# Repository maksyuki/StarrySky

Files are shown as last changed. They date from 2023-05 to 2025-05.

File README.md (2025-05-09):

<p align="center">
    <!-- <img width="200px" src="./.images/tree_core_logo.svg" align="center" alt="Tree Core CPU" /> -->
    <h2 align="center">StarrySky: A series of Single-board Computers(SBCs) based on OSOC SoC</h2>
</p>
<p align="center">
    <a href="./LICENSE">
      
    </a>
    <a href="./CONTRIBUTING.md">
      
    </a>
    <a href="https://github.com/maksyuki/StarrySky">
      
    </a>
</p>

The StarrySky is now fully Open Source Hardware Association Certified.

UID:CN000018 https://certification.oshwa.org/list.html



Hardware, software and documentation licensed under the GPL v3 license.

## Guide
* StarrySky introduction: https://ysyx.oscc.cc/chip/board/official
* StarrySky V1.2: https://ysyx.oscc.cc/chip/board/official/boards/board-1
* StarrySky V1.3: https://ysyx.oscc.cc/chip/board/official/boards/board-2
* StarrySky V2.1: https://ysyx.oscc.cc/chip/board/official/boards/board-3
* StarrySky V3.0: come soon!
## Overview
The StarrySky SBC(Single Board Computer) was launched by Yuchi Miao in March 2023. It is used to evaluate and showcase the rich peripheral applications of the One Student One Chip SoC. The long-term goal is to build a lightweight software and hardware ecosystem around the Starry Sky boards and explore rich application scenarios in the field of education.







## License
All of the contents in this repo are release under the [GPL-3.0 License](LICENSE).

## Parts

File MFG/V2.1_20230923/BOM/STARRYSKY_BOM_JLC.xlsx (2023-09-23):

Comment | Designator | Footprint | Quantity
10uF | CP1,CP2 | AEC-2-5R40X4R00-SM | 2
0.1uF | C1,C2,C8,C9,C12,C13,C17,C18,C19,C20,C27,C28,C29,C30,C31,C32,C33,C34,C35,C36,C37,C38,C41,C42,C43,C44,C45,C46,C47,C48,C49,C50,C51,C52,C53,C54,C55,C56,C57,C58,C59,C60,C61,C62,C63,C64,C66,C67,C68,C69,C71,C72,C73,C74,C76,C78,C79,C80,C81,C82,C83,C84,C85,C86,C88,C89,C90,C91,C92,C93,C97,C98,C99,C101,C104,C105,C106,C107,C108,C110,C112,C115,C116,C117,C118,C119,C120,C121,C122,C123,C124,C125,C126,C128,C129,C131,C134,C144,C146,C148,C149,C155,C156,C160,C162,C163,C164,C165,C166,C167,C168,C170,C172,C174,C176,C177,C181,C182,C183,C185,C186,C192 | C0402 | 122
10uF | C3,C5,C6,C10,C11,C14,C21,C23,C24,C25,C26,C70,C87,C94,C95,C103,C130,C132,C133,C150,C169,C171,C173 | C0402 | 23
1uF | C4,C15,C22,C65,C102,C143,C145,C147,C154,C157,C161,C175,C178 | C0402 | 13
15pF | C7,C16,C109,C111 | C0402 | 4
22nF | C39 | C0402 | 1
10nF | C40 | C0402 | 1
10pF | C75,C77 | C0402 | 2
18pF | C96,C100 | C0402 | 2
100pF | C113 | C0402 | 1
47pF | C114 | C0402 | 1
2.2uF | C127 | C0402 | 1
22uF | C135,C136,C137,C138,C139,C141 | C0402 | 6
20pF | C140,C142,C151,C152,C153 | C0402 | 5
39pF | C158,C159,C179,C180 | C0402 | 4
330pF | C184,C187,C189,C190 | C0402 | 4
NC | C188,C191 | C0402 | 2
SMAJ5.0CA | D1 | SMA-2R00X1R80 | 1
0805_2A | F1 | L0805 | 1
FIXING-HOLE | H1,H2,H3,H4 | HOLE-3R10-4R10 | 4
USB_PWR | J1 | USB-TYPEC-12-SM | 1
100MHz | J2 | XTAL-4-3R20X2R50-SM | 1
DC_PWR | J3 | USB-TYPEC-12-SM | 1
25MHz | J4 | XTAL-4-3R20X2R50-SM | 1
SD_MICRO | J5,J7 | SD-MICRO-9-SM | 2
ACA-SPI-004-K02 | J6,J13 | ACA-SPI-004-K02-SM | 2
JTAG | J8 | HDR5X2-2R54-TM-VF | 1
PS_PWR | J9 | USB-TYPEC-12-SM | 1
USB_HOST | J10 | USB-STD-TYPEA-4-SM | 1
PS2_PURPLE | J11 | PS2-6-TM-VF | 1
VGA | J12 | DE-15-TM-RF | 1
FPC-8 | J14 | FPC-8-0R50-0R80X0R30 | 1
AUD_OUT | J15 | AV-6-2R30X1R60-SM | 1
PL_SD | J16 | SD-MICRO-9-SM | 1
AUD_IN | J17 | AV-6-2R30X1R60-SM | 1
LSPK | J18 | PH-2R00-TM-VM | 1
USB_PL_UART | J19 | USB-TYPEC-12-SM | 1
RSPK | J20 | PH-2R00-TM-VM | 1
PL_EXTN | J21 | HDR20X2-1R27-SM-VF | 1
DF40C-100DS-0.4V | J22,J23,J24,J25 | B2B-100-0R40-SM-VF | 4
RED | LED1 | LED0603 | 1
BLUE | LED2,LED3,LED4,LED5 | LED0603 | 4
WS2812C | LED6,LED7,LED8,LED9 | LED5050 | 4
600OHM@100MHz 1.5A | L1,L2,L3,L4,L5,L6,L7 | L0805 | 7
180OHM@100MHz 1.5A | L8,L9 | L0805 | 2
RUM001L02T2CL | Q1,Q2,Q3 | SOT-723-3-0R49X0R29 | 3
56K | R1 | R0402 | 1
2K | R2,R44,R60,R81,R104,R105,R110,R154,R156 | R0402 | 9
5.1K | R3,R7,R86,R89,R179,R181 | R0402 | 6
NC | R4,R6,R11,R12,R18,R69,R77,R83,R109,R111,R183 | R0402 | 11
33R | R5,R13,R51,R70,R99,R138,R140,R142,R147,R148,R149,R150,R151,R153,R155,R185 | R0402 | 16
4.7K | R8,R14,R48,R49,R50,R52,R53,R54,R55,R56,R57,R64,R65,R68,R72,R74,R75,R84,R91,R96,R103,R106,R107,R108,R128,R129,R130,R131,R144,R145,R146,R157,R159,R160,R173,R174,R176 | R0402 | 37
10K | R9,R15,R19,R34,R58,R61,R62,R63,R85,R88,R93,R112,R115,R133,R162,R163 | R0402 | 16
26K | R10 | R0402 | 1
8.06K | R16,R102 | R0402 | 2
1K | R17,R90,R152 | R0402 | 3
0R | R20,R22,R24,R30,R37,R38,R43,R45,R46,R47,R95,R98,R100,R101,R135,R137,R143,R158,R161,R164,R165,R168,R169,R170,R175,R177,R178,R180,R182,R184 | R0402 | 30
5K | R21,R23,R25,R28,R29,R31,R32,R33,R35,R36,R39,R40,R41,R42 | R0402 | 14
1M | R26,R97 | R0402 | 2
14K | R27 | R0402 | 1
330R | R59 | R0402 | 1
20K | R66,R67,R76,R78,R79,R80,R82 | R0402 | 7
150R | R71,R73 | R0402 | 2
22R | R87 | R0402 | 1
1.5K | R92 | R0402 | 1
100K | R94 | R0402 | 1
1740R | R113,R120,R124 | R0402 | 3
100R | R114,R118,R136,R139,R141 | R0402 | 5
866R | R116,R121,R125 | R0402 | 3
430R | R117,R122,R126 | R0402 | 3
215R | R119,R123,R127 | R0402 | 3
5.1R | R132 | R0402 | 1
4.7R | R134 | R0402 | 1
30K | R166,R167,R171,R172 | R0402 | 4
PWR-SEL1 | SW1 | SW-3-12R7X6R6 | 1
PWR-SEL2 | SW2 | SW-3-12R7X6R6 | 1
PWR-LOCK | SW3 | SW-6-LOCK-DPDT-TM | 1
PLL-SEL | SW4 | DIP-SW-4-1R27X0R76-SM | 1
CLK-SEL | SW5 | DIP-SW-8-1R52X0R76-SM | 1
SOC-RESET | SW6 | SW-4-1R20X0R65-SM | 1
CORE-SEL | SW7 | DIP-SW-6-1R27X0R76-SM | 1
HFP-SW | SW8 | SW-6-SLIDE-DPDT-TM | 1
HFP-RESET | SW9 | SW-4-1R20X0R65-SM | 1
HFP-BOOT | SW10 | SW-4-1R20X0R65-SM | 1
HFP-USER | SW11 | SW-4-1R20X0R65-SM | 1
PS-EXT-RESET | SW12 | SW-4-1R20X0R65-SM | 1
FPGA-BOOT | SW13 | DIP-SW-2-1R52X0R76-SM | 1
PS-PWR-RESET | SW14 | SW-4-1R20X0R65-SM | 1
PS-KEY1 | SW15 | SW-4-1R20X0R65-SM | 1
PS-KEY2 | SW16 | SW-4-1R20X0R65-SM | 1
PERIP-SW | SW17 | SW-6-SLIDE-DPDT-TM | 1
PL-KEY | SW18 | SW-4-1R20X0R65-SM | 1
PA-SW | SW19 | SW-6-SLIDE-DPDT-TM | 1
OSC_25M_IN | TP1 | TP1X1-1R00-SM | 1
OSC_100M_IN | TP2 | TP1X1-1R00-SM | 1
CLK4DIV | TP3 | TP1X1-1R00-SM | 1
HFP_VCC_3V3 | TP4 | TP1X1-1R00-SM | 1
HFP_SWDIO | TP5 | TP1X1-1R00-SM | 1
HFP_SWCLK | TP6 | TP1X1-1R00-SM | 1
HFP_GND | TP7 | TP1X1-1R00-SM | 1
RT2515H | U1,U2,U4 | SOIC-8-1R80X0R60-THRM | 3
SOC-28NM-202301 | U3 | LQFP-144-1R80X0R28 | 1
LPSDRAM_16X16 | U5 | FBGA-54-0R36-8R00X8R00 | 1
TPS3808G01 | U6 | SOT-23-6-1R10X0R60 | 1
WAS3157B | U7,U9,U10,U11,U12,U14,U26,U27,U29,U30,U31,U32,U33,U34,U35,U36,U37,U38,U39,U40,U44,U45 | SOT-363-6-0R80X0R40 | 22
CP2102 | U8,U22,U50 | QFN-28-0R90X0R25 | 3
TXS0108E | U13,U19,U41,U53 | TSSOP-20-1R50X0R45 | 4
TXS0102 | U15,U20,U25,U42,U43,U46,U52 | VSSOP-8-0R80X0R30 | 7
STM/CH32V103C8T6 | U16 | LQFP-48-1R20X0R30 | 1
W25Q128JVSIQ | U17 | SOIC-8-2R25X0R63 | 1
RCLAMP0524P | U18 | DFN-10-0R68X0R20 | 1
TPS2051BDBV | U21 | SOT-23-5-1R10X0R60 | 1
USB3320C | U23 | QFN-32-0R80X0R28 | 1
AT24C64 | U24 | SOIC-8-1R80X0R60 | 1
PCF8563B | U28 | SOIC-8-1R80X0R60 | 1
ES8388 | U47 | QFN-28-0R66X0R22 | 1
LPSDRAM_32X16 | U48 | FBGA-54-0R36-8R00X8R00 | 1
NS4150B | U49,U51 | MSOP-8-1R70X0R35 | 2
8MHz 10pF 10PPM | X1 | XTAL-4-3R20X2R50-SM | 1
24MHz 12pF | X2 | XTAL-4-3R20X2R50-SM | 1
32.768KHz 12.5pF 20PPM | X3 | XTAL-2-3R20X1R50-SM | 1
50MHz | X4 | XTAL-4-3R20X2R50-SM | 1

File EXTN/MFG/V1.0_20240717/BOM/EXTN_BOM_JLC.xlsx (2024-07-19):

Comment | Designator | Footprint | Quantity
0.1uF | C1,C2,C7,C9,C10,C11,C14,C15,C16 | C0402 | 9
10uF | C3,C5,C6,C12,C13 | C0402 | 5
1uF | C4,C8 | C0402 | 2
EXTN | J1 | HDR4X1-2R54-TM-VM | 1
USB_PL_UART | J2 | USB-TYPEC-12-SM | 1
PL_EXTN | J3 | HDR20X2-1R27-SM-VF | 1
26K | R1 | R0402 | 1
0R | R2,R3,R5,R6 | R0402 | 4
10K | R4,R7,R11 | R0402 | 3
4.7K | R8,R12 | R0402 | 2
5.1K | R9,R10 | R0402 | 2
PL-KEY | SW1 | SW-4-1R20X0R65-SM | 1
RT2515H | U1 | SOIC-8-1R80X0R60-THRM | 1
CP2102 | U2 | QFN-28-0R90X0R25 | 1
APS51208N-OBR | U3 | BGA-24-0R40-8R00X6R00 | 1
W25Q128JVSIQ | U4 | SOIC-8-2R25X0R63 | 1
TXS0108E | U5 | TSSOP-20-1R50X0R45 | 1

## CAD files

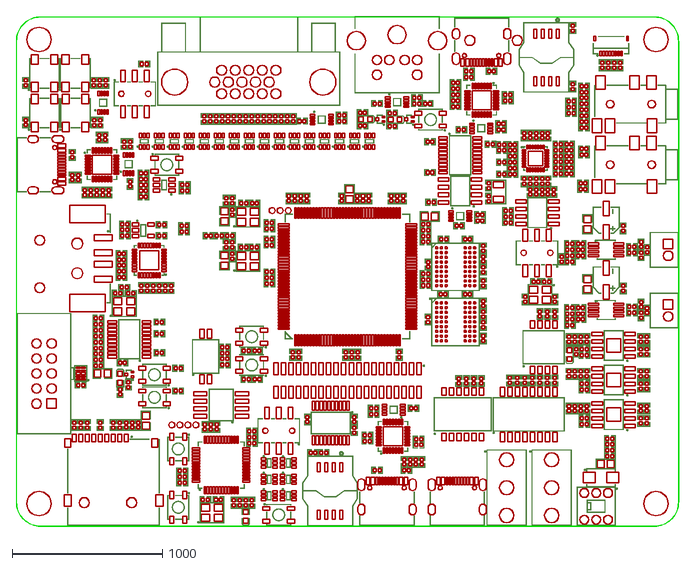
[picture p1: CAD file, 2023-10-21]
CAD/V2.1/STARRYSKY.dxf
4406.0 x 3390.8

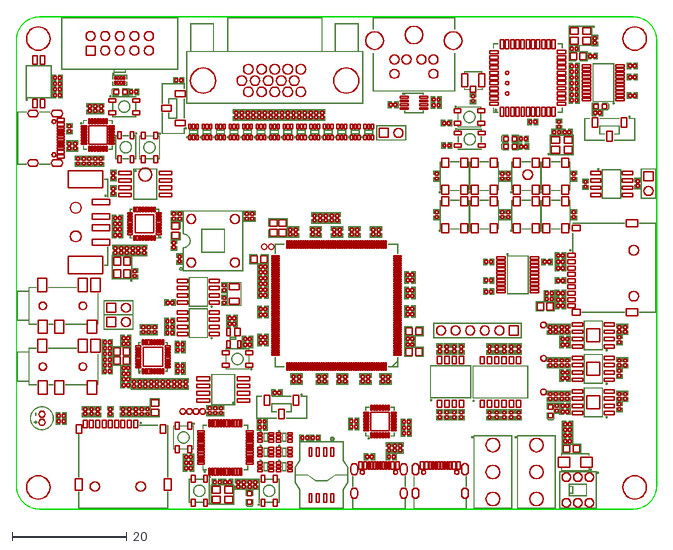
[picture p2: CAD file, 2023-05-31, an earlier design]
CAD/V1.3/STARRYSKY.dxf
111.9 x 86.1

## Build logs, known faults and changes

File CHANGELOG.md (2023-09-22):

## V2.1
- 修改W25Q128JVSIQ的封装1脚标识
- 删除电源使能端的两个电阻
- SoC时钟输入更换表贴的25MHz和100MHz有源晶振
- 放大测试点之间的间距
- 更换FPC-8为双接的器件
- 重新设计顶层logo的丝印
- 板卡内层空白区域覆铜

## V2.0
- 更换FPGA核心板及其接插件设计
- 重新设计1.8V标准的SoC和FPGA端外设电路
- 更换音频DAC为ES8388
- 添加PL端UART，TF，TFT-LCD，SDRAM等外设
- 重新设计PS端UART HOST电路

## V1.3
- 更换三期第二批的芯片

## V1.2
- 修改PS/2插座的PCB封装
- 修改电源按动开关的SMT方向

## V1.1
- 使用Xilinx 7Z010核心板设计
- 引出核心板上所有的引脚
- 添加板载烧写器
- 重新设计电源网络
- 设计I2C，SPI，GPIO，VGA和PS/2等外设

## V1.0
- 添加初版设计

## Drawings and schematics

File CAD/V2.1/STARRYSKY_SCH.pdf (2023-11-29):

D

D

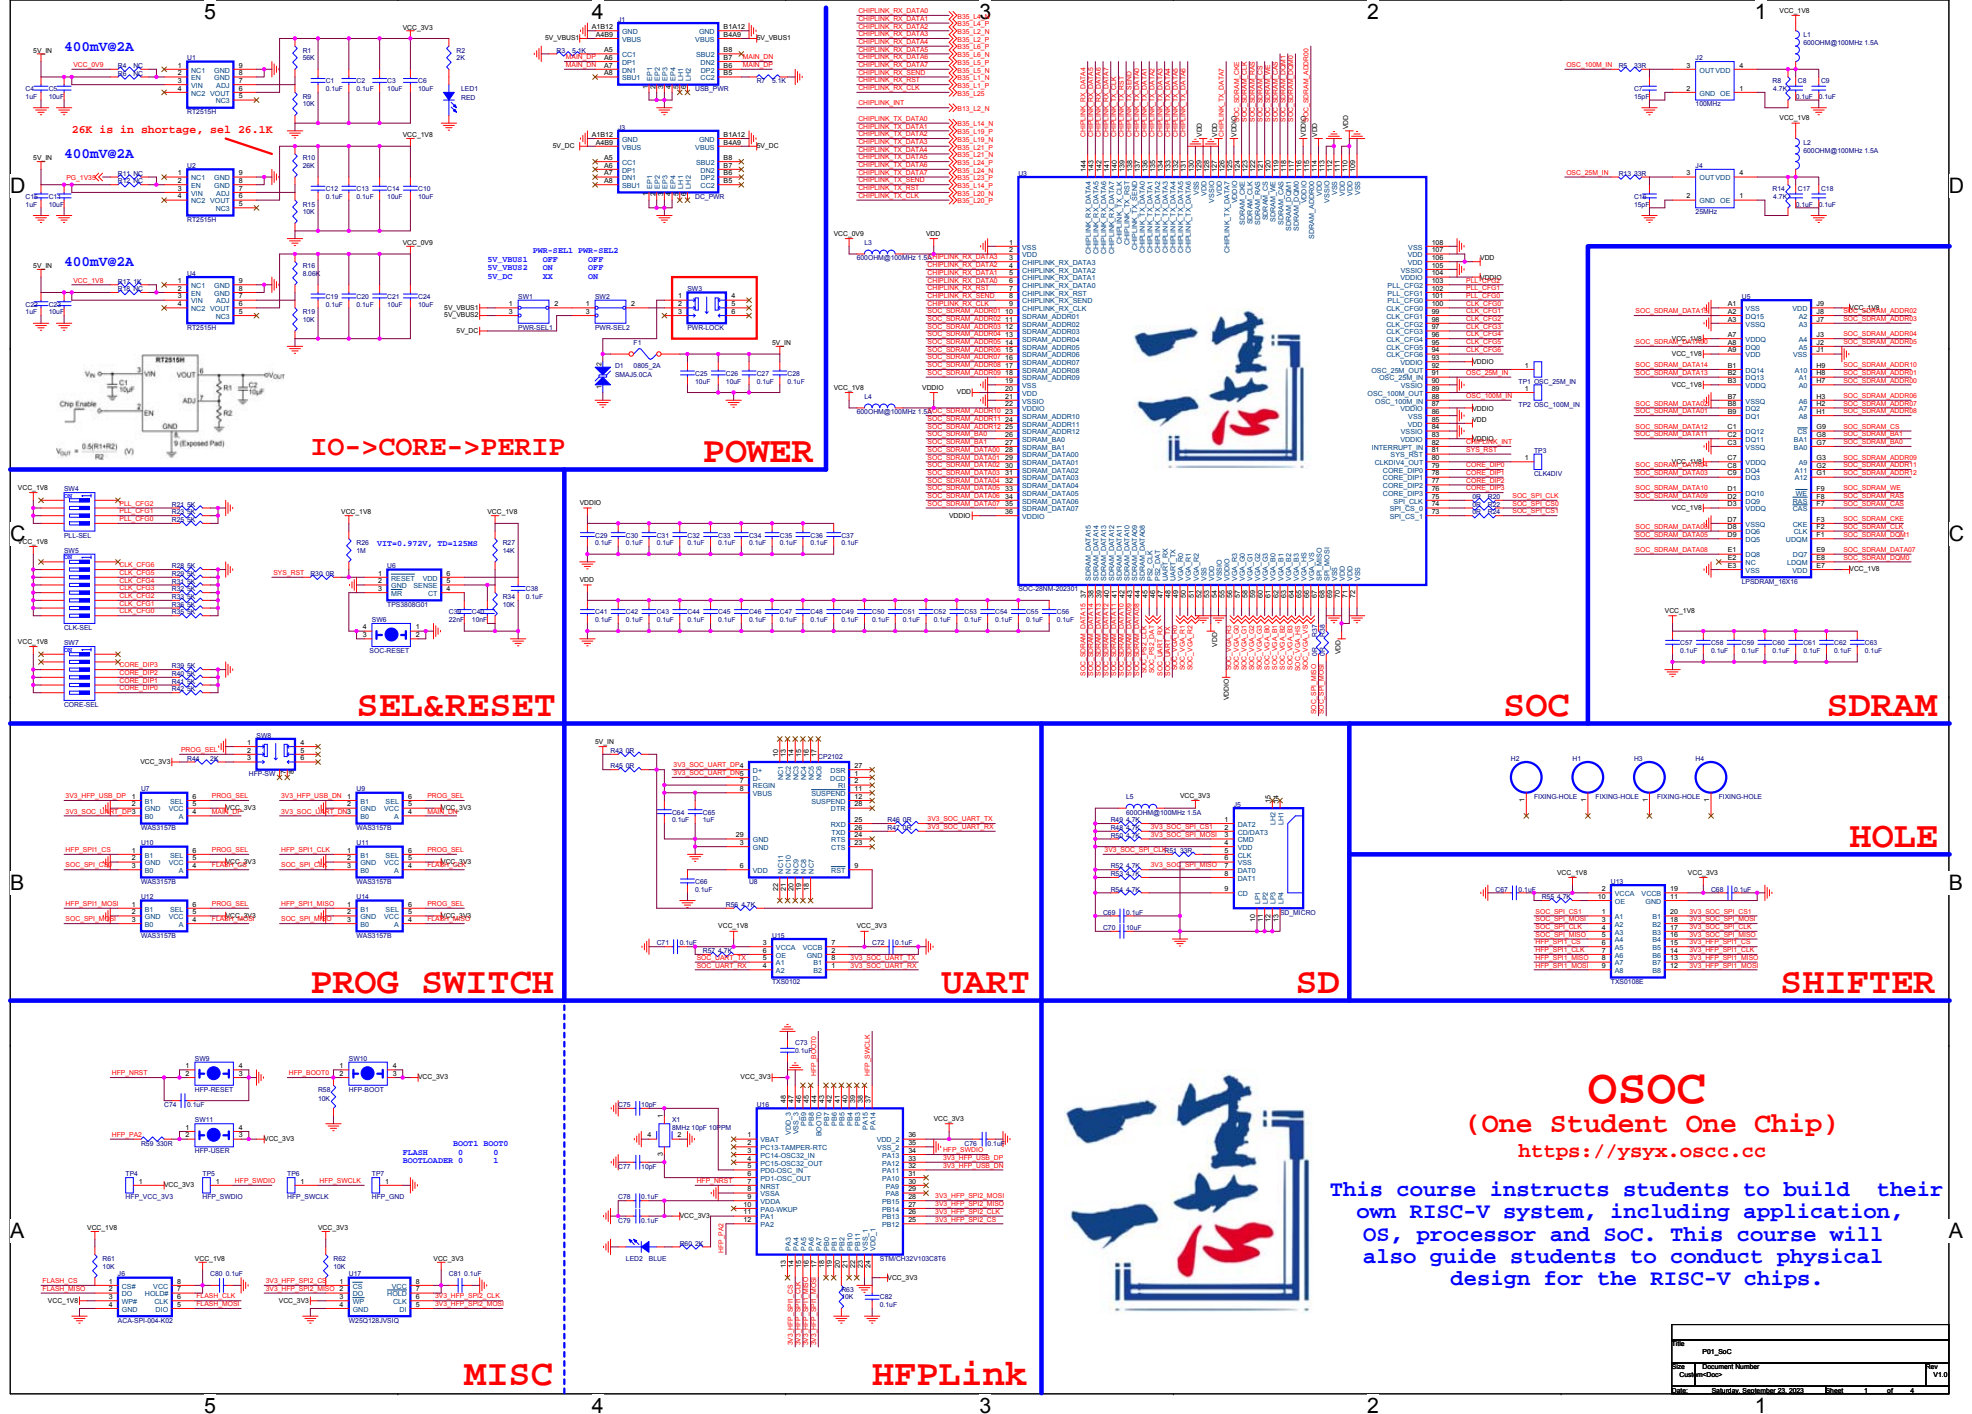
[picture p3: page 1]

26K is in shortage, sel 26.1K

VCC_1V8 SW4 | SOC_SDRAM_DATA03 VDDIO | SDRAM_DATA03 31

CLK_CFG4 | GND 2

(One Student One Chip)

This course instructs students to build their
own RISC-V system, including application,
OS, processor and SoC. This course will
also guide students to conduct physical

PA2 12 | 3V3_HFP_SPI2_CS

design for the RISC-V chips.

5

4

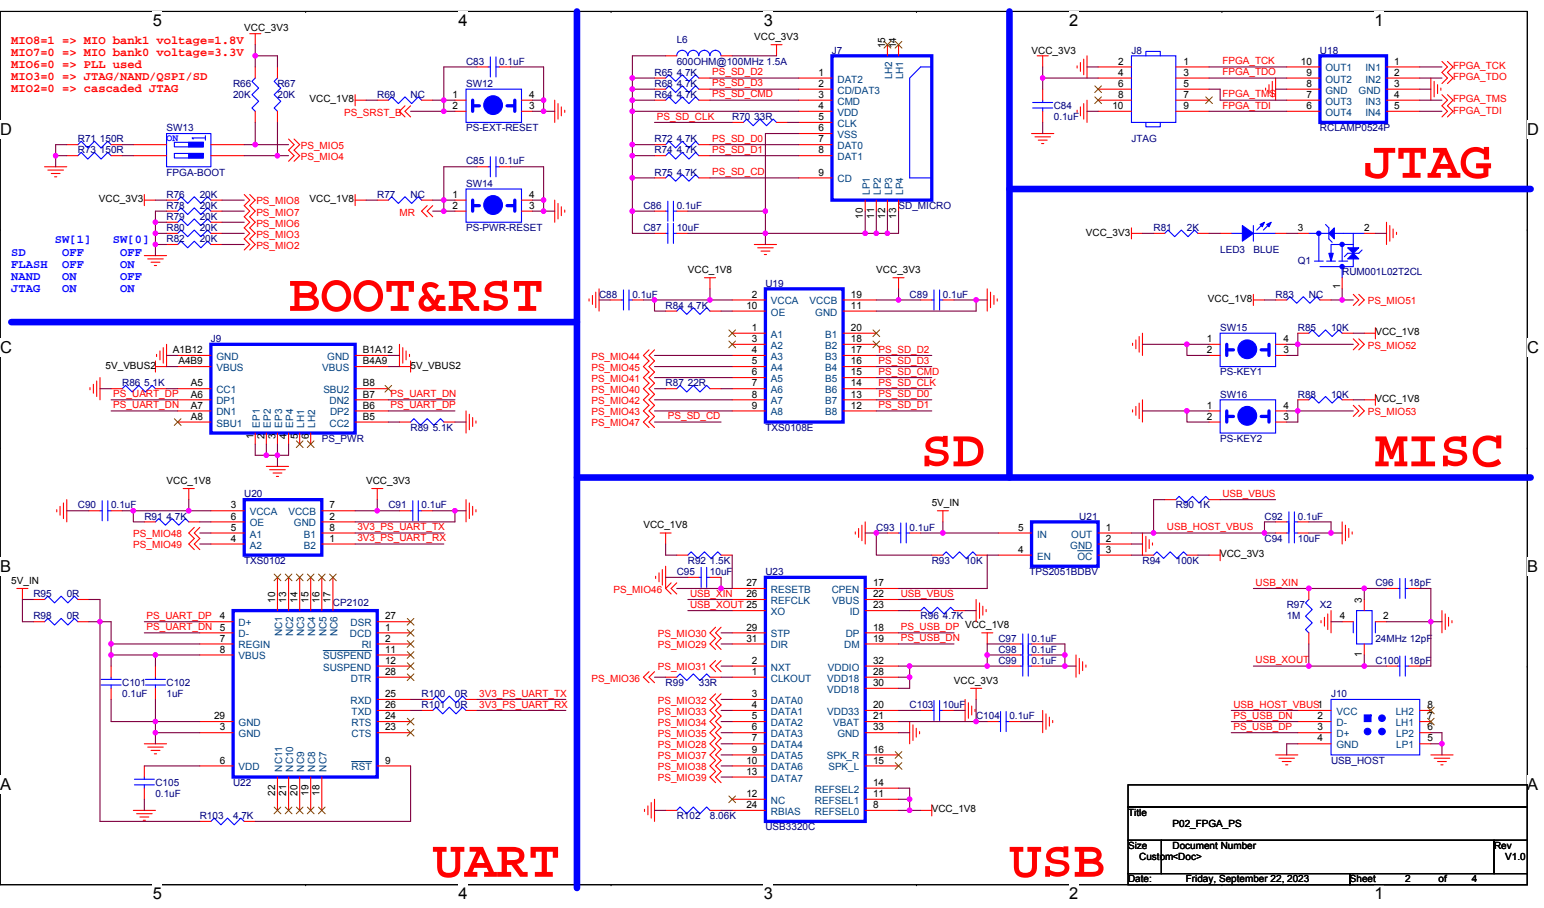
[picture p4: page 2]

MIO8=1 => MIO bank1 voltage=1.8V
MIO7=0 => MIO bank0 voltage=3.3V
MIO6=0 => PLL used
MIO3=0 => JTAG/NAND/QSPI/SD
MIO2=0 => cascaded JTAG

MISC

USB_VBUS

Size Size Size Custom Custom Custom | Document Number Document Number Document Number <Doc> <Doc> <Doc> | Rev Rev Rev V1.0 V1.0 V1.0

Date: Date: Date: Friday, September 22, 2023 Friday, September 22, 2023 Friday, September 22, 2023 | Sheet Sheet Sheet 2 2 2 of of of 4 4 4

5 | 4 | 3 | 2 | 1

D

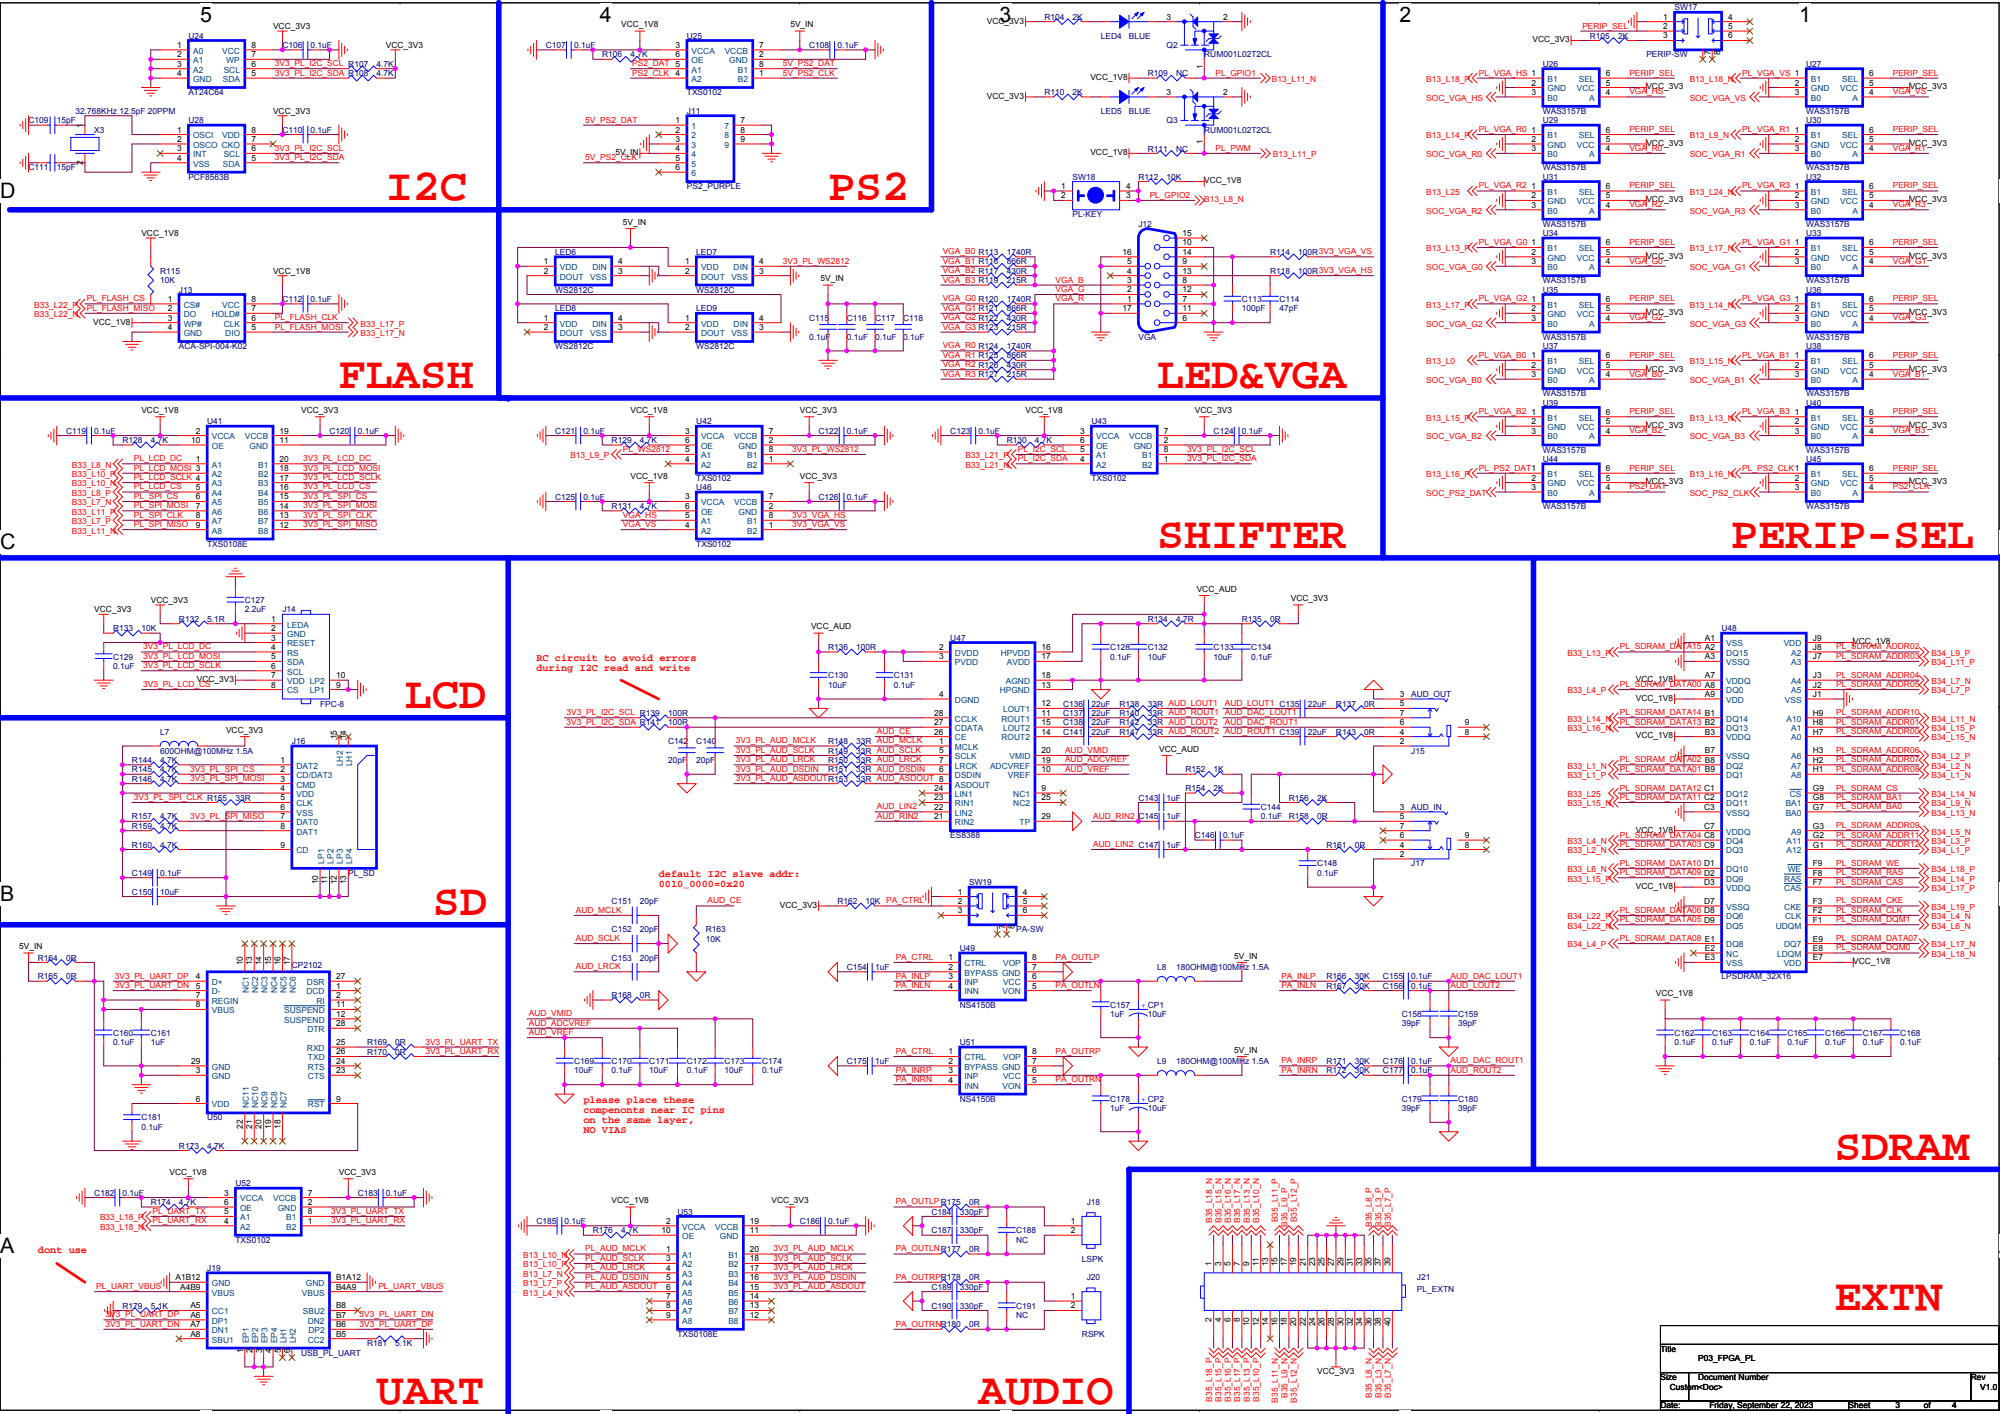
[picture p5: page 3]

RC circuit to avoid errors
during I2C read and write

please place these
compenonts near IC pins
on the same layer,
NO VIAS

D

## VCC_B13

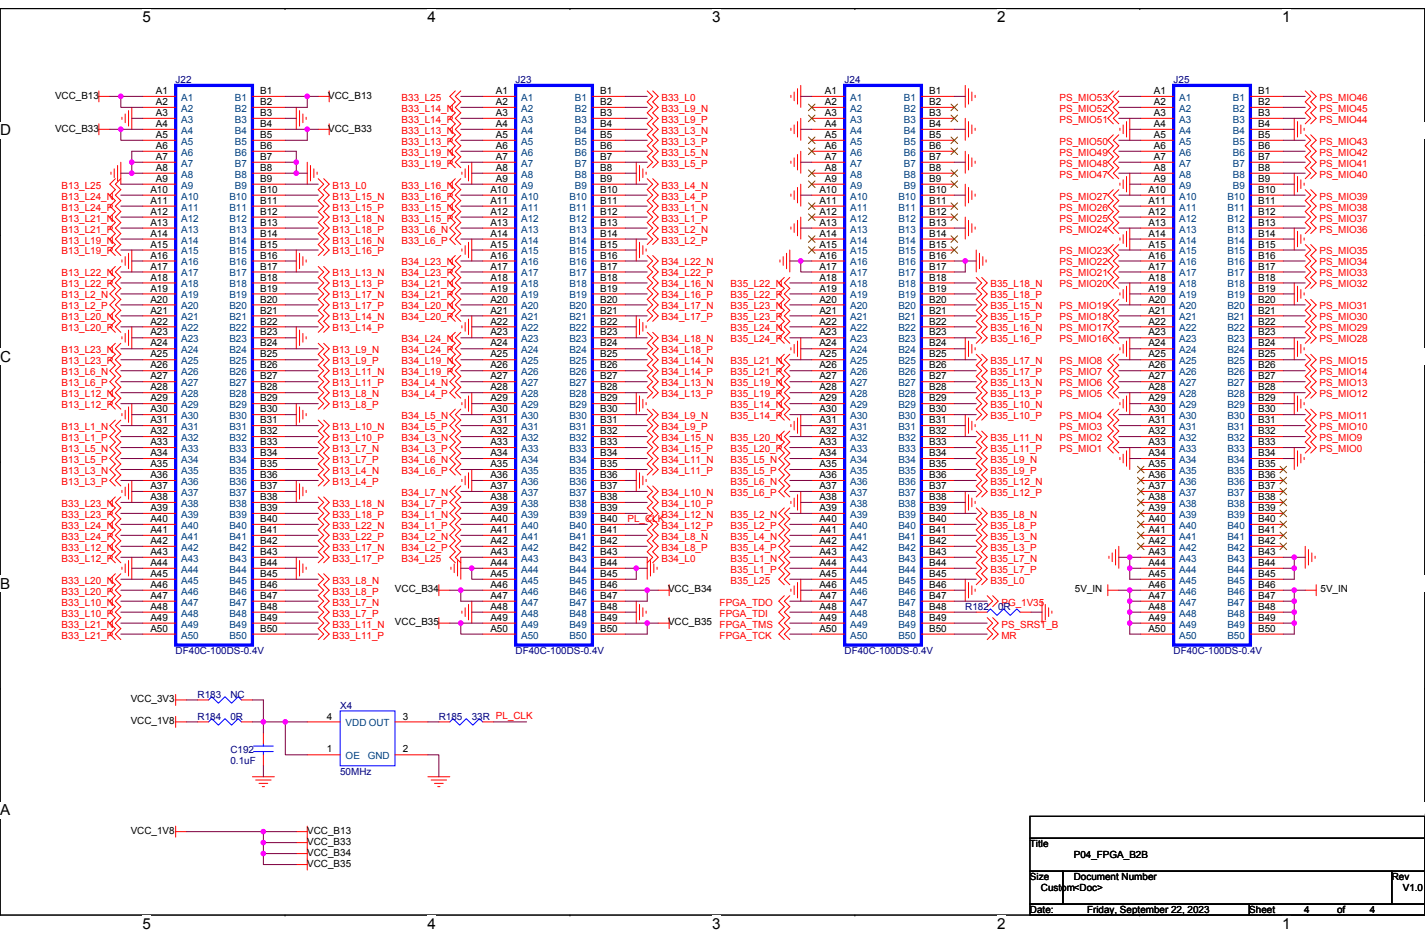
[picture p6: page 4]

Size Size Size | Document Number Document Number Document Number | Rev Rev Rev

Friday, September 22, 2023 Friday, September 22, 2023 Friday, September 22, 2023 | 4 4 4

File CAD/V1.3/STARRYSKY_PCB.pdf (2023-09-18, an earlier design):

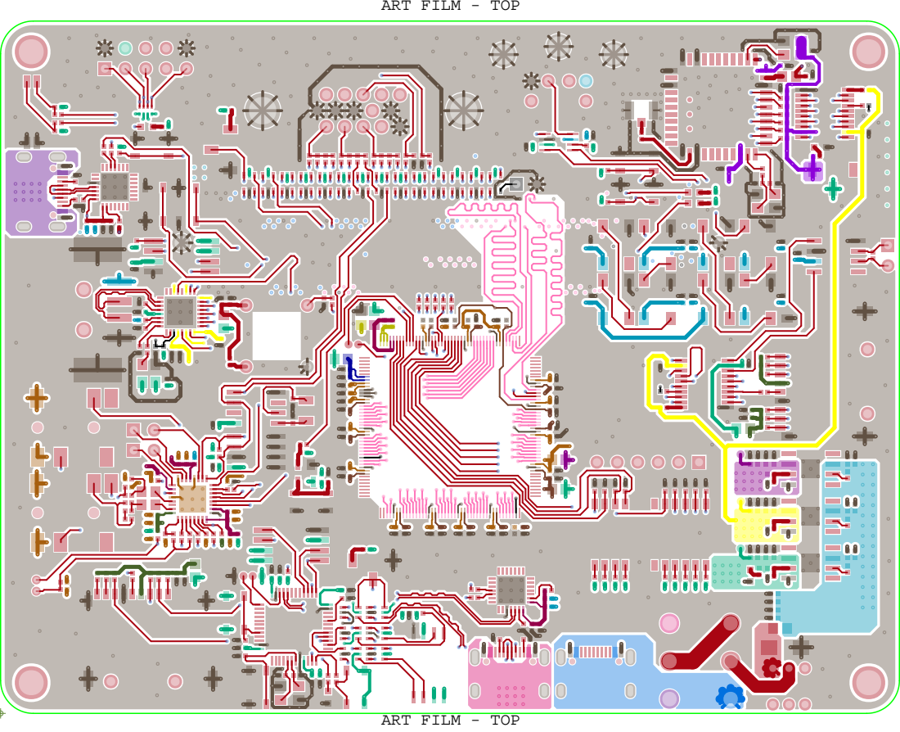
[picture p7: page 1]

ART FILM - TOP

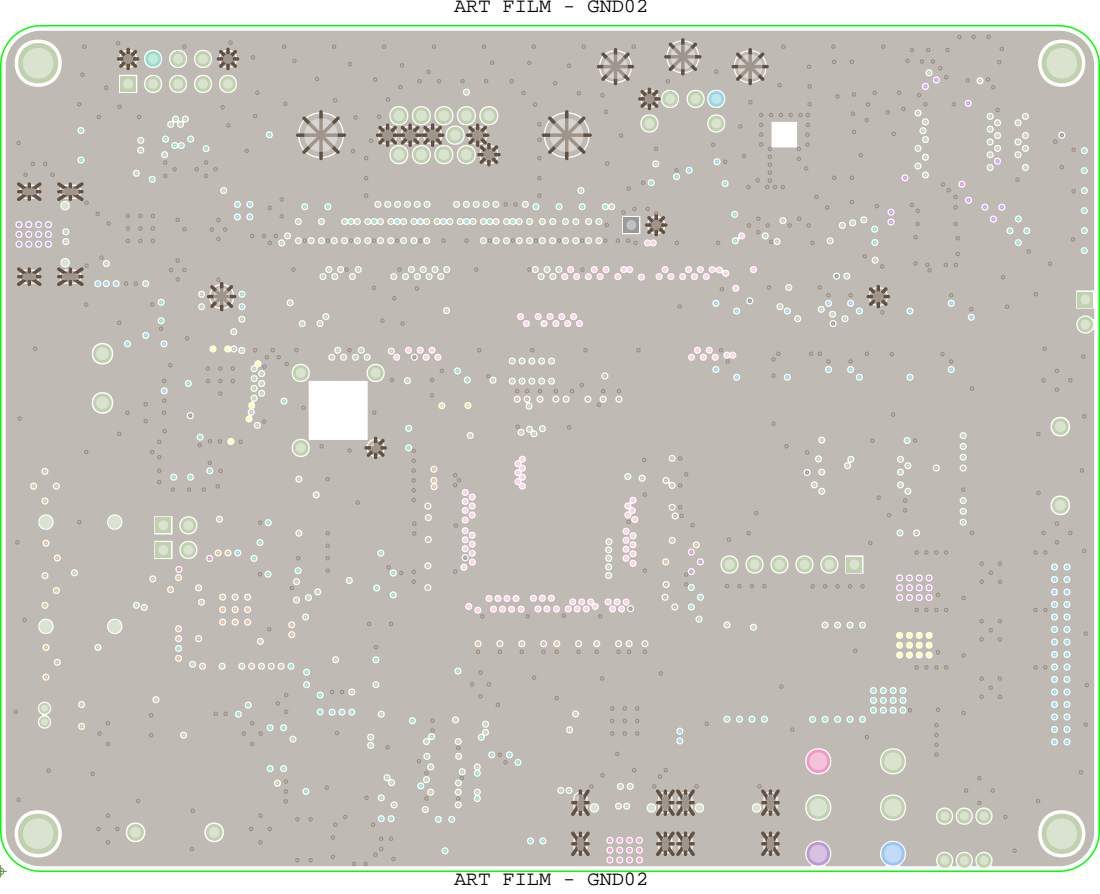
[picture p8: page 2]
ART FILM - GND02

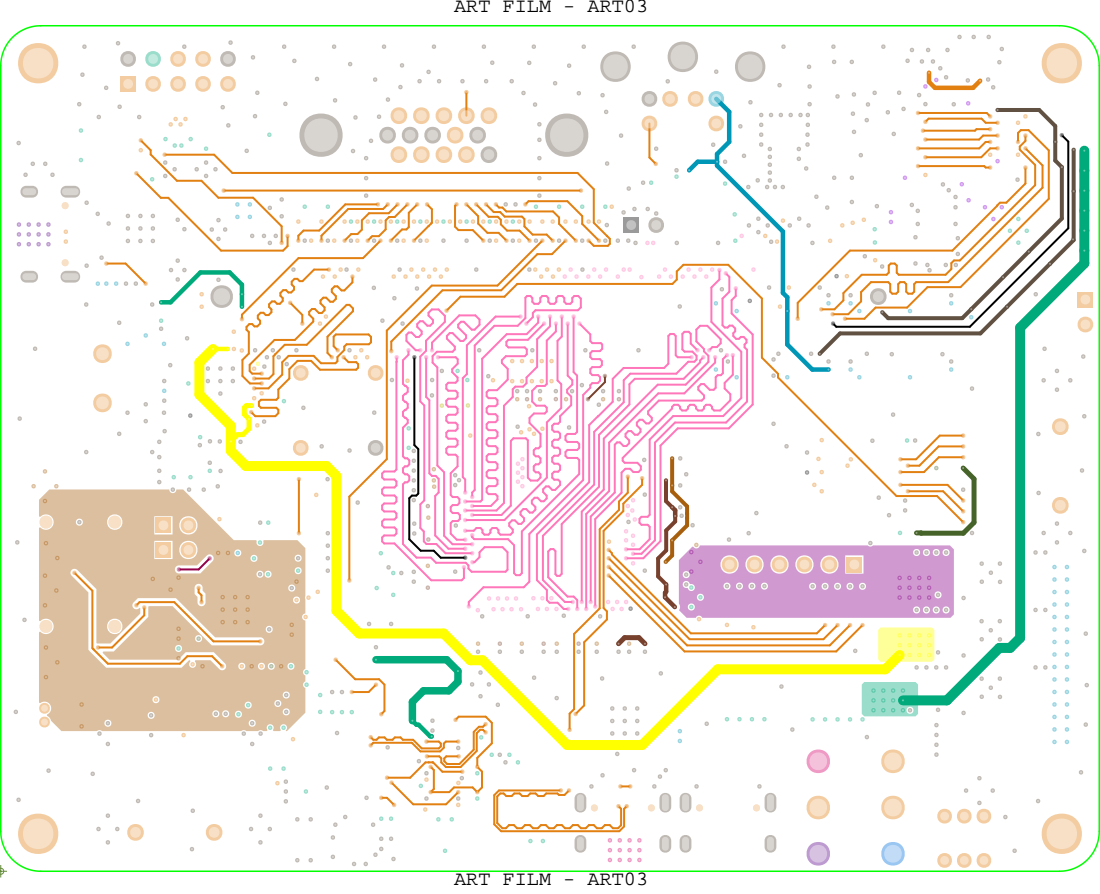
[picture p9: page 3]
ART FILM - ART03

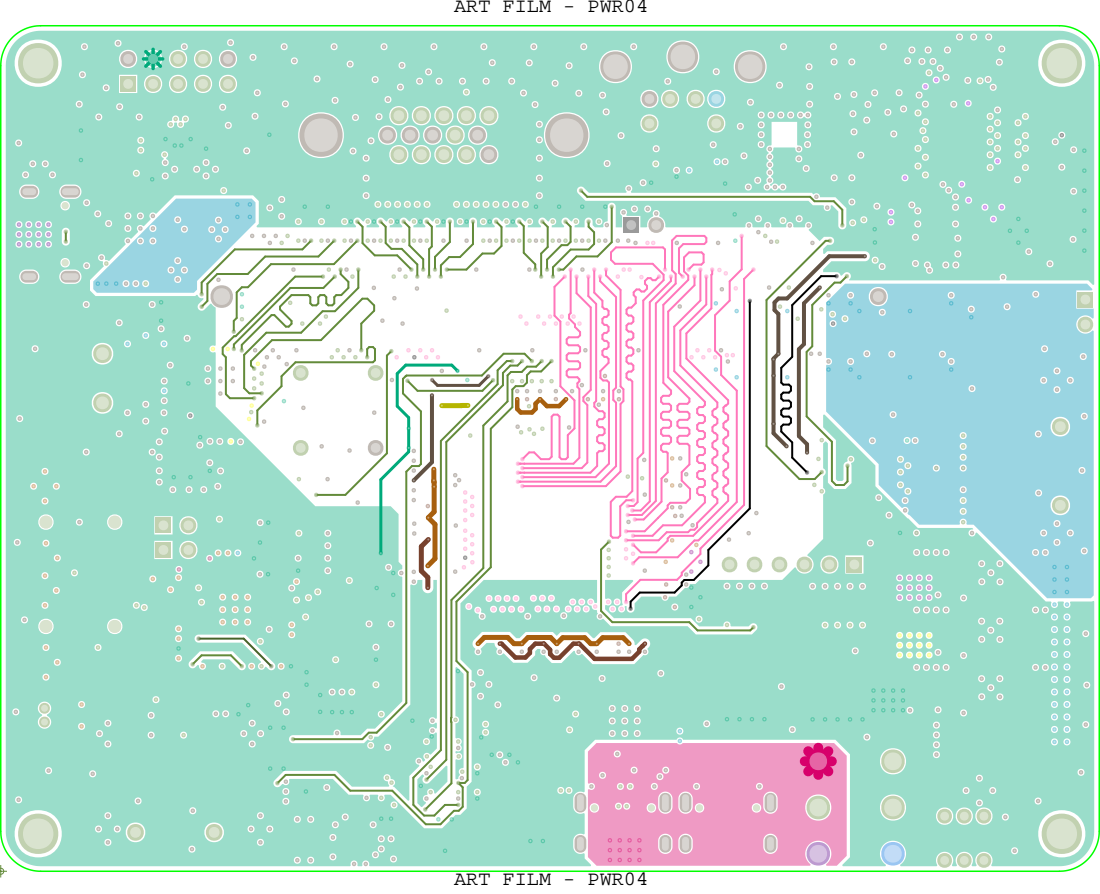
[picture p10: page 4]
ART FILM - PWR04

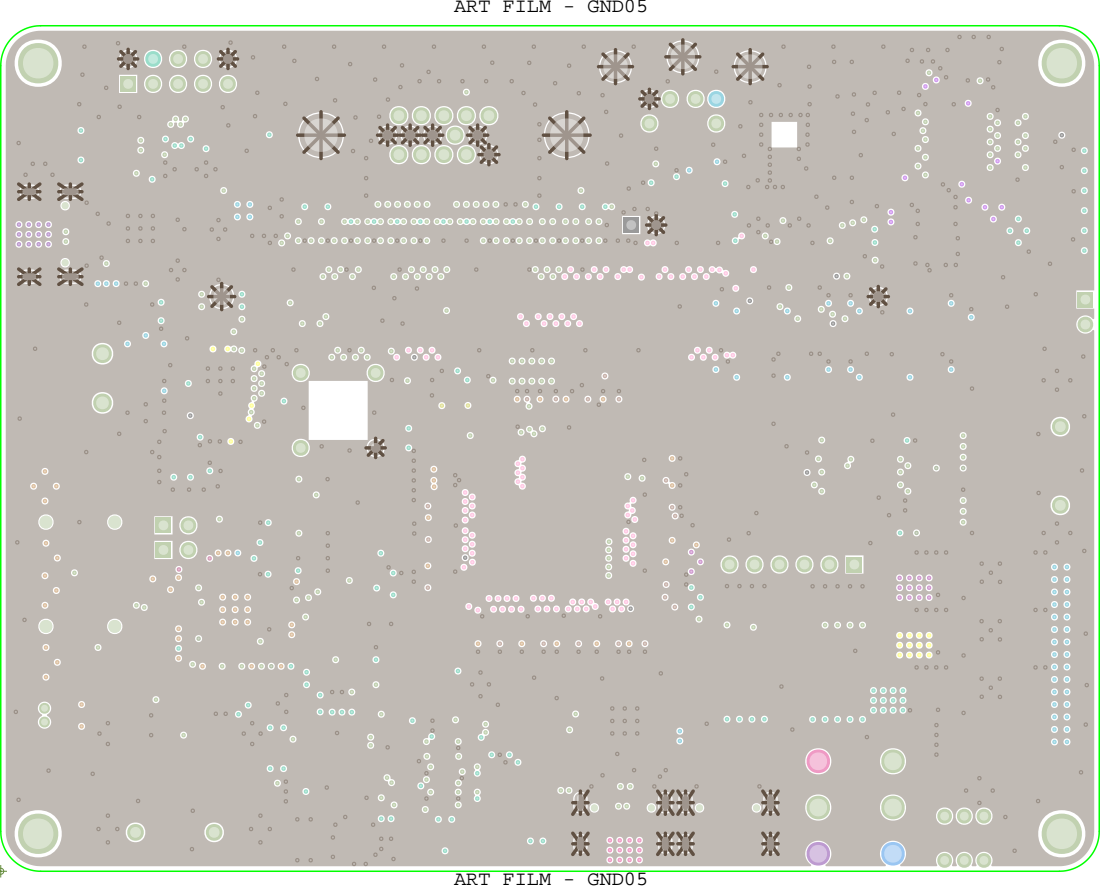
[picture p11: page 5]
ART FILM - GND05

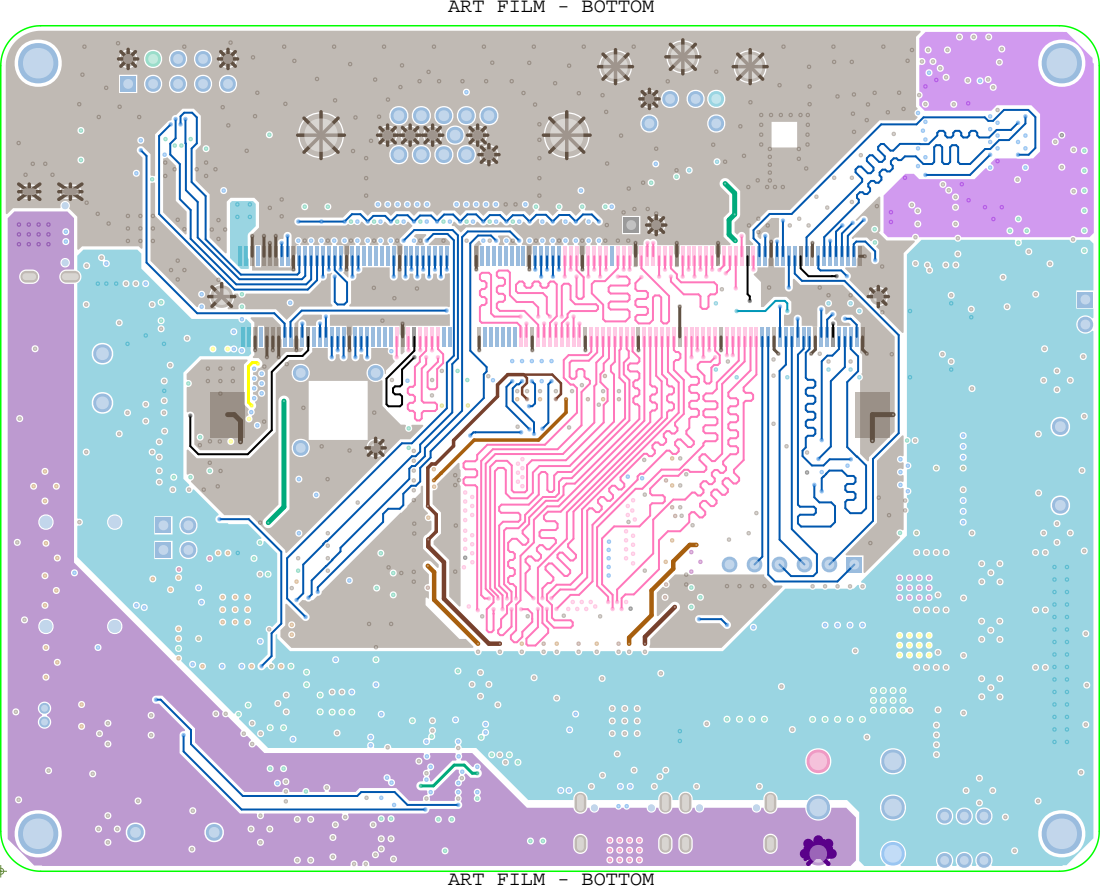
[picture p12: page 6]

ART FILM - BOTTOM

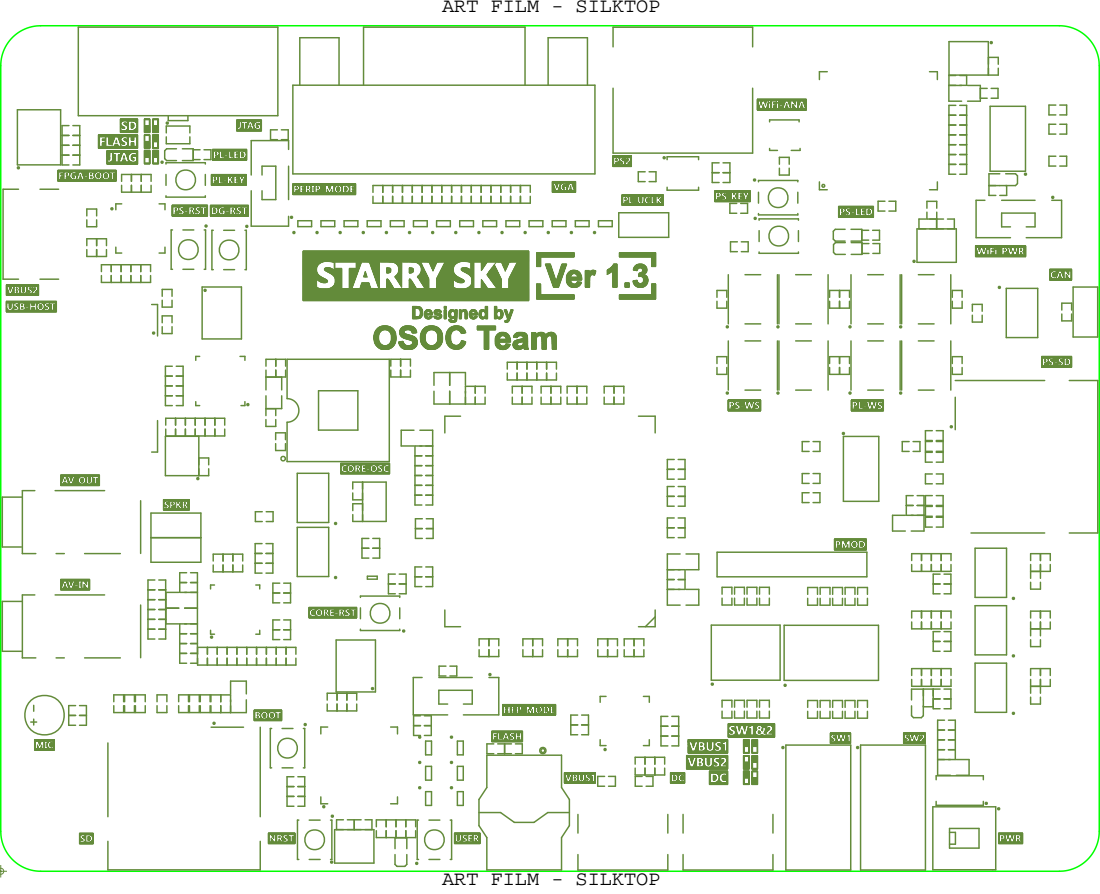
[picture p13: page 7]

ART FILM - SILKTOP

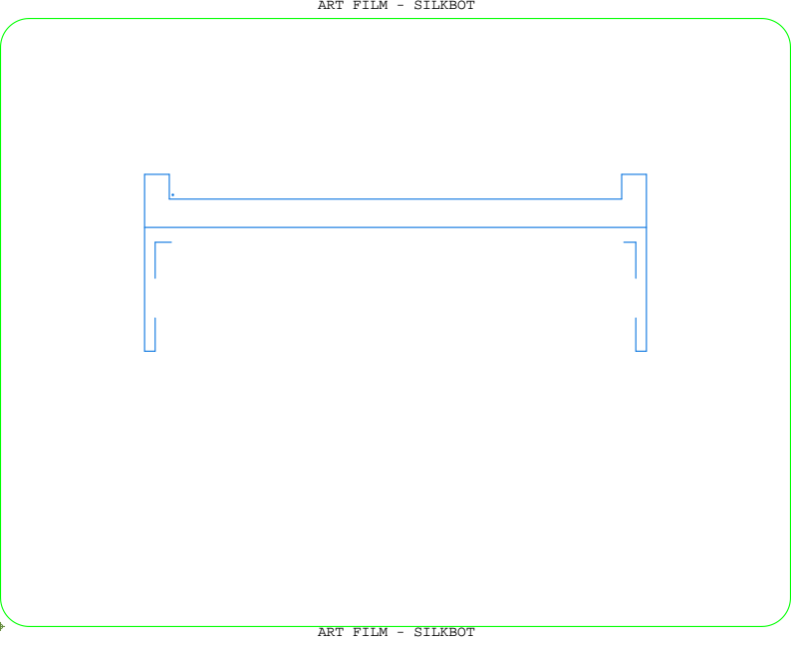
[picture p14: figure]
ART FILM - SILKBOT

ART FILM - SOLDTOP


ART FILM - SOLDBOT


ART FILM - PASTTOP

ART FILM - PASTBOT
ART FILM - DRILL; QTY; PLATED; SIZE; ALL UNITS ARE IN MILS; DRILL CHART:; TOP; to BOTTOM; FIGURE

ART FILM - DRILL

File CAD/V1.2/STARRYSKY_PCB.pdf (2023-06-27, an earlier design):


ART FILM - TOP

ART FILM - GND02

ART FILM - ART03

ART FILM - PWR04

ART FILM - GND05


ART FILM - BOTTOM


ART FILM - SILKTOP

ART FILM - SILKBOT

ART FILM - SOLDTOP


ART FILM - SOLDBOT


ART FILM - PASTTOP

ART FILM - PASTBOT
ART FILM - DRILL; QTY; PLATED; SIZE; ALL UNITS ARE IN MILS; DRILL CHART: TOP; to BOTTOM; FIGURE

ART FILM - DRILL

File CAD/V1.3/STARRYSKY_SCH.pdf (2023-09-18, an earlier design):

D

D


RT-Thread Capable,RISC-V SoC
The second edition uses 7Z7010 FPGA
core board to set up memory access
system(32-bits DDR3) with ChipLink bus.

26K is in shortage, sel 26.1K

NC30 133 NC31 134 CHIPLINK_RX_DATA24 135 CHIPLINK_RX_DATA25 136 VSS 137 VDD 138 VDDIO 139 CHIPLINK_RX_DATA26 140 CHIPLINK_RX_DATA27 141 CHIPLINK_RX_DATA28 142 CHIPLINK_RX_DATA29 143 CHIPLINK_RX_DATA30 144 CHIPLINK_RX_DATA31 145 CHIPLINK_TX_CLK 146 CHIPLINK_TX_RST 147 VSS 148 VDD 149 VDDIO 150 CHIPLINK_TX_SEND 151 CHIPLINK_TX_DATA00 152 CHIPLINK_TX_DATA01 153 CHIPLINK_TX_DATA02 154 CHIPLINK_TX_DATA03 155 CHIPLINK_TX_DATA04 156 VSS 157 VDD 158 VDDIO 159 CHIPLINK_TX_DATA05 160 CHIPLINK_TX_DATA06 161 CHIPLINK_TX_DATA07 162 CHIPLINK_TX_DATA08 163 CHIPLINK_TX_DATA09 164 CHIPLINK_TX_DATA10 165 CHIPLINK_TX_DATA11 166 VSS 167 VDD 168 VDDIO 169 CHIPLINK_TX_DATA12 170 CHIPLINK_TX_DATA13 171 CHIPLINK_TX_DATA14 172 CHIPLINK_TX_DATA15 173 CHIPLINK_TX_DATA16 174 CHIPLINK_TX_DATA17 175 NC32 176

(One Student One Chip)

This course instructs students
to build their own RISC-V
system, including application,
OS, processor and SoC.
This course will also guide

PA2 12 | HFP_SPI2_CS

students to conduct physical
design for the RISC-V chips.

SW[1] SW[0] D | L8 | 5V_IN CAN

D


600HM 100MHz 1.5A R63 4.7K PS_SD_D2 R61 4.7K R62 4.7K | DAT2 1

Custom Custom Custom

Thursday, June 01, 2023 Thursday, June 01, 2023 Thursday, June 01, 2023 | 2 2 2 4 4 4

D | D
I2C


4K is in shortage, sel 4.7K

Thursday, June 01, 2023 Thursday, June 01, 2023 Thursday, June 01, 2023 | 3 3 3 4 4 4

5 | 4 | 3 | 2 | 1

D

PS_POR_B DONT USE; V5_NC DONT USE; PL_GCLK DONT USE; QSPI_D3 PS_MIO0; PS_MIO9 PS_MIO7; RESET_POR PS_SRST_B PS_MIO34 PS_MIO32 PS_MIO29; PS_MIO39 PS_MIO28 PS_MIO30; QSPI_D2 PS_MIO8; FPGA_TMS FPGA_TDI FPGA_TDO FPGA_TCK PS_MIO36 PS_MIO33 PS_MIO38 PS_MIO37; PS_MIO31; PS_MIO35; IO35_20_N IO35_20_P IO35_6_P IO35_6_N IO35_3_N IO35_3_P PS_MIO25 PS_MIO21; PS_MIO16 PS_MIO23 PS_MIO24 PS_MIO26 PS_MIO42 PS_MIO44; PS_MIO47 PS_MIO50 PS_MIO48 PS_MIO52 PS_MIO53 PS_MIO43 PS_MIO51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

11 | | 12
13 | | 14

Thursday, June 01, 2023 Thursday, June 01, 2023 Thursday, June 01, 2023 | 4 4 4

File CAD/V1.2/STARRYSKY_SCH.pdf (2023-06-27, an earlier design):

D

D


RT-Thread Capable,RISC-V SoC
The second edition uses 7Z7010 FPGA
core board to set up memory access
system(32-bits DDR3) with ChipLink bus.

26K is in shortage, sel 26.1K

CHIPLINK_RX_DATA24 133 CHIPLINK_RX_DATA25 134 VSS 135 VDD 136 VDDIO 137 CHIPLINK_RX_DATA26 138 CHIPLINK_RX_DATA27 139 CHIPLINK_RX_DATA28 140 CHIPLINK_RX_DATA29 141 CHIPLINK_RX_DATA30 142 CHIPLINK_RX_DATA31 143 CHIPLINK_TX_CLK 144 CHIPLINK_TX_RST 145 VSS 146 VDD 147 VDDIO 148 CHIPLINK_TX_SEND 149 CHIPLINK_TX_DATA00 150 CHIPLINK_TX_DATA01 151 CHIPLINK_TX_DATA02 152 CHIPLINK_TX_DATA03 153 CHIPLINK_TX_DATA04 154 VSS 155 VDD 156 VDDIO 157 CHIPLINK_TX_DATA05 158 CHIPLINK_TX_DATA06 159 CHIPLINK_TX_DATA07 160 CHIPLINK_TX_DATA08 161 CHIPLINK_TX_DATA09 162 CHIPLINK_TX_DATA10 163 CHIPLINK_TX_DATA11 164 VSS 165 VDD 166 VDDIO 167 CHIPLINK_TX_DATA12 168 CHIPLINK_TX_DATA13 169 CHIPLINK_TX_DATA14 170 CHIPLINK_TX_DATA15 171 CHIPLINK_TX_DATA16 172 CHIPLINK_TX_DATA17 173 VSS 174 VDD 175 VDDIO 176

(One Student One Chip)

This course instructs students
to build their own RISC-V
system, including application,
OS, processor and SoC.
This course will also guide

PA2 12 | HFP_SPI2_CS

students to conduct physical
design for the RISC-V chips.

SW[1] SW[0] D | L8 | 5V_IN CAN

D


600HM 100MHz 1.5A R63 4.7K PS_SD_D2 R61 4.7K R62 4.7K | DAT2 1

Custom Custom Custom

Wednesday, May 31, 2023 Wednesday, May 31, 2023 Wednesday, May 31, 2023 | 2 2 2 4 4 4

D | D
I2C


4K is in shortage, sel 4.7K

Wednesday, May 31, 2023 Wednesday, May 31, 2023 Wednesday, May 31, 2023 | 3 3 3 4 4 4

5 | 4 | 3 | 2 | 1

D

PS_POR_B DONT USE; V5_NC DONT USE; PL_GCLK DONT USE; QSPI_D3 PS_MIO0; PS_MIO9 PS_MIO7; RESET_POR PS_SRST_B PS_MIO34 PS_MIO32 PS_MIO29; PS_MIO39 PS_MIO28 PS_MIO30; QSPI_D2 PS_MIO8; FPGA_TMS FPGA_TDI FPGA_TDO FPGA_TCK PS_MIO36 PS_MIO33 PS_MIO38 PS_MIO37; PS_MIO31; PS_MIO35; IO35_20_N IO35_20_P IO35_6_P IO35_6_N IO35_3_N IO35_3_P PS_MIO25 PS_MIO21; PS_MIO16 PS_MIO23 PS_MIO24 PS_MIO26 PS_MIO42 PS_MIO44; PS_MIO47 PS_MIO50 PS_MIO48 PS_MIO52 PS_MIO53 PS_MIO43 PS_MIO51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

11 | | 12
13 | | 14

Wednesday, May 31, 2023 Wednesday, May 31, 2023 Wednesday, May 31, 2023 | 4 4 4

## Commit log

2023-05-31 docs: add action flows and modify guide files
2023-05-31 feat: add v1.2 dxf file
    [STARRYSKY.dxf]
2023-05-31 feat: add multi ver sch design files
    [STARRYSKY.DSN]
2023-05-31 feat: add multi ver pcb design files
2023-05-31 feat: add multi ver mfg files
    [STARRYSKY_BOM_JLC.xlsx, STARRYSKY_XY_JLC.xlsx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]
2023-06-05 feat: add v1.3 sch design
    [STARRYSKY.DSN]
2023-06-05 feat: add v1.3 pcb design
2023-06-06 feat: modify v1.3 sch and pcb
2023-06-06 feat: add v1.3 MFG design files
    [STARRYSKY_BOM_JLC.xlsx, STARRYSKY_XY_JLC.xlsx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]
2023-06-27 feat: add v1.2 sch, pcb and dxf files
    [STARRYSKY.dxf]
2023-07-19 feat: modify v1.3 mfg xy file
    [STARRYSKY_XY_JLC.xlsx]
2023-07-23 feat: modify v2.0 sch design
    [STARRYSKY.DSN]
2023-07-28 feat: modify v2.0 pcb design
    [STARRYSKY.DSN]
2023-08-11 feat: modify sch and pcb design
    [STARRYSKY.DSN]
2023-08-12 feat: add v2.0 sch design
    [STARRYSKY.DSN]
2023-08-22 feat: modify v1.2 pcb design
2023-08-28 feat: add v2.0 mfg files
    [STARRYSKY_BOM_JLC.xlsx, STARRYSKY_XY_JLC.xlsx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]
2023-09-18 feat: add v1.3 cad files
2023-09-22 feat: add v2.1 sch design
    [STARRYSKY.DSN]
2023-09-22 feat: add v2.1 pcb design file
2023-09-23 feat: modify v2.1 pcb design
2023-09-23 feat: modify v2.1 sch design
    [STARRYSKY.DSN]
2023-09-23 feat: add v2.1 mfg files
    [STARRYSKY_BOM_JLC.xlsx, STARRYSKY_XY_JLC.xlsx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]
2023-10-21 feat: add v2.1 cad design
    [STARRYSKY.dxf]
2023-11-29 feat: add v2.1 cad design files
    [STARRYSKY.dxf]
2024-07-18 feat: add extn board sch
    [EXTN.DSN]
2024-07-19 feat: add extn board pcb design file
    [EXTN.brd]
2024-07-19 feat: add extn board mfg files
    [EXTN_BOM_JLC.xlsx, EXTN_XY_JLC.xlsx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]
